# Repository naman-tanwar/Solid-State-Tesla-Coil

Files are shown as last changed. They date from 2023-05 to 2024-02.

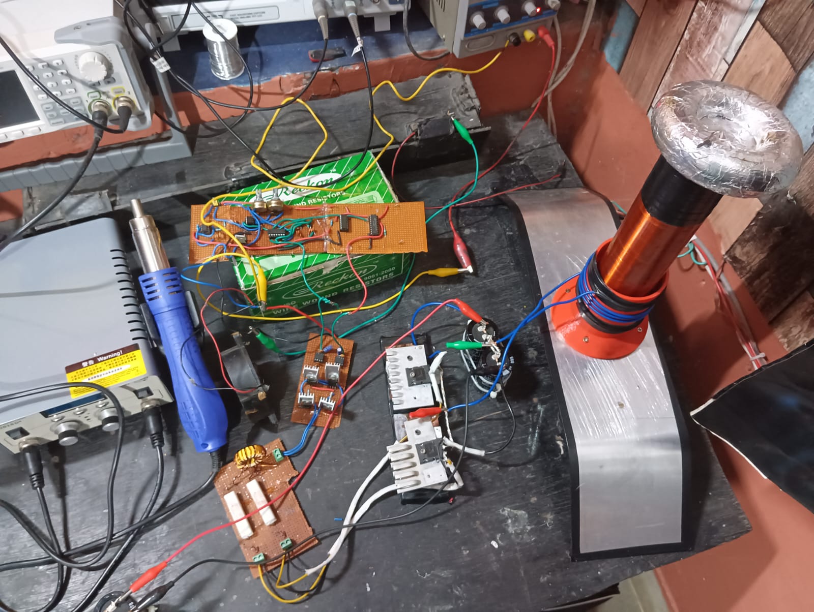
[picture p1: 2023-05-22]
Photos/Setup - Pic2.jpg

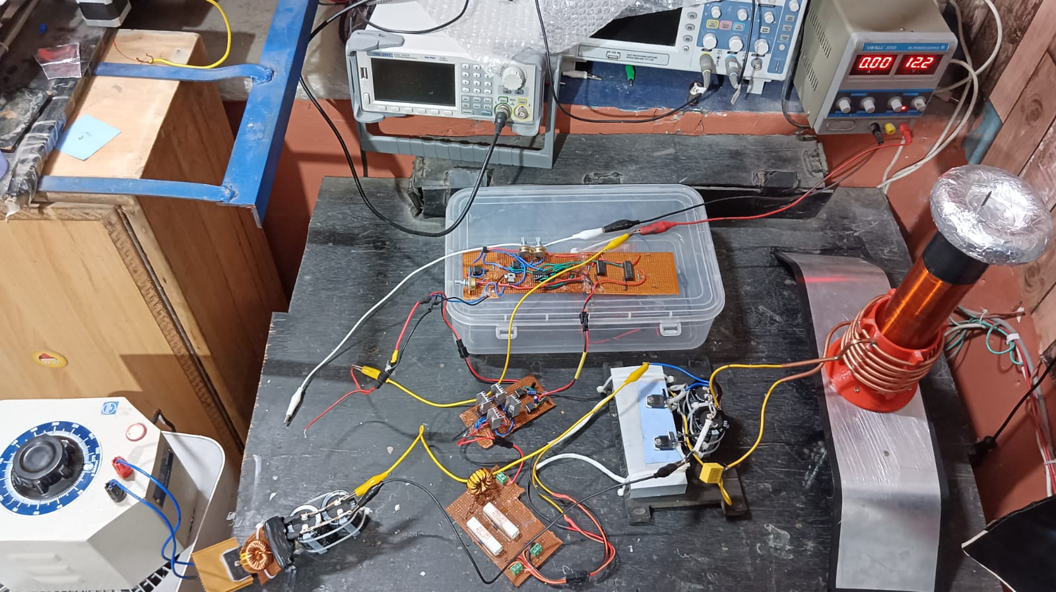
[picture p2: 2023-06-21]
Photos/Setup - Pic3.jpg

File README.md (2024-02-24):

#### This project is published in IEEE Access, do check the complete article: [10.1109/ACCESS.2024.3357534](https://doi.org/10.1109/ACCESS.2024.3357534)
# Solid State Tesla Coil (SSTC)
N|TeslaCoil

## Introduction
Solid State Tesla Coil uses transistor-based switching devices (instead of Spark Gap) to resonate the secondary coil with or without feedback. 
The both kinds of circuits (with and without feedback) were designed and implemented.
The features of the SSTC are:
1. Feedback and without feedback Circuits
2. Variable duty cycle Interrupter
3. Music Interrupter to play music from SSTC
4. PCB Design

## Design
The design of the tesla coil is described below,
### Coil Design
1. Primary Coil  <br>
Primary Coil consist of 5mm copper pipe with 6 turns wound around the secondary with 3D printed support.  <br>
2. Secondary Coil  <br>
The secondary winding are wound around a 2-inch PVC water pipe with 36 gauge copper motor winding wire. The length of the pipe is around 25cm with winding height of 20cm. 5cm of PVC pipe is kept as a margin.
Around 1200 turns of described wire was winded.  <br>
3. Top Load  <br>
The top load was 3D printed in two halves and then aluminium tape was wrapped around it. The tape was wrapped with as much wrinkles as possible to reduce charge loss. The 3D files are available to download on this GitHub page  <br>
5. 3D printed holder for coils  <br>
Using Fusion 360, the coil holder was designed. The files for the holder can also be downloaded from this github page.  <br>

### Circuit Design
As described in the Introduction section, the different circuits were designed to incorporate all the features. Before actually implementing tho, these were simulated using LTSpice. <br>
The Complete circuit diagram and all the simulation files are available on this page.

### PCB Design
N|TeslaCoilPCB

A PCB was designed using Altium. The PCB is a 4 layer board with 100mm x 100mm dimensions. All generic parts THT parts were used in this design.
The features of the PCB are:
1. It uses tuneable non-feedback circuit
2. Can also play music. The music input can be given using 3.5mm mobile AUX cable.
3. Circuit is tested with voltages from 12V to 15V  
<br>
The gerber files, Bill Of Material (BOM), Altium project files and other related documents are available to download from this page.

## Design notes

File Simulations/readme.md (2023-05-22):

# Simulation Info
To verify the design of the tesla coil various simulations were performed using LTspice. These simulations were:

1. Gate Drive Signal Generation

Here we used 555 timer IC (U1) to generate around 730KHz signal. R1, R2 are the potentiometers that can be tuned to produce required frequency.
This signal goes through various Schmitt triggers to produce required output. The R,C,D component reduces the ON pulse width so that a margin of dead time can be created between the two output drives.
The Drive1 is complementary of Drive2 with a little dead time between those two pulses.
Now, an another 555 timer IC (U2) is used to interrupt the produced drive signal at much lower frequency (<1KHz). The duty cycle of the interrupt signal can be adjusted by adjusting R6. Although it will also change the frequency but it will remain less than 1KHz.

2. Music Input

An OPAMP based PWM signal generation from music signal is simulated. Generally, from the mobile audio jack the output voltage is 0.8V peak. Hence it need to be first amplified. The OPAMP U1 amplify the signal and the OPAMP U2 acts as a comparator to output PWM signal.
The reference Voltage of the comparator can be adjusted by adjusting the R5 resistor Value.
In practice, LM358 Dual OPAMP IC was used.

3. Feedback Tesla Coil

This circuit uses an antenna as a feedback to self-sustain the oscillations. (Basically an advance version of Slayer Exciter) Here the interrupter is also implemented by simply connecting the feedback to the interrupt signal through a Diode. 
Resistor selection R1, R2, R3 is also important to reduce overloading effect (in case of R1) and to sustain the oscillations.
Diodes D3 and D4 are to limit input voltage to 5V

4. Diode Voltage Limiting

This circuit simulates the voltage limiting using two fast recovery diodes.

5. Slayer Exciter

Simulates traditional BJT based slayer exciter circuit.

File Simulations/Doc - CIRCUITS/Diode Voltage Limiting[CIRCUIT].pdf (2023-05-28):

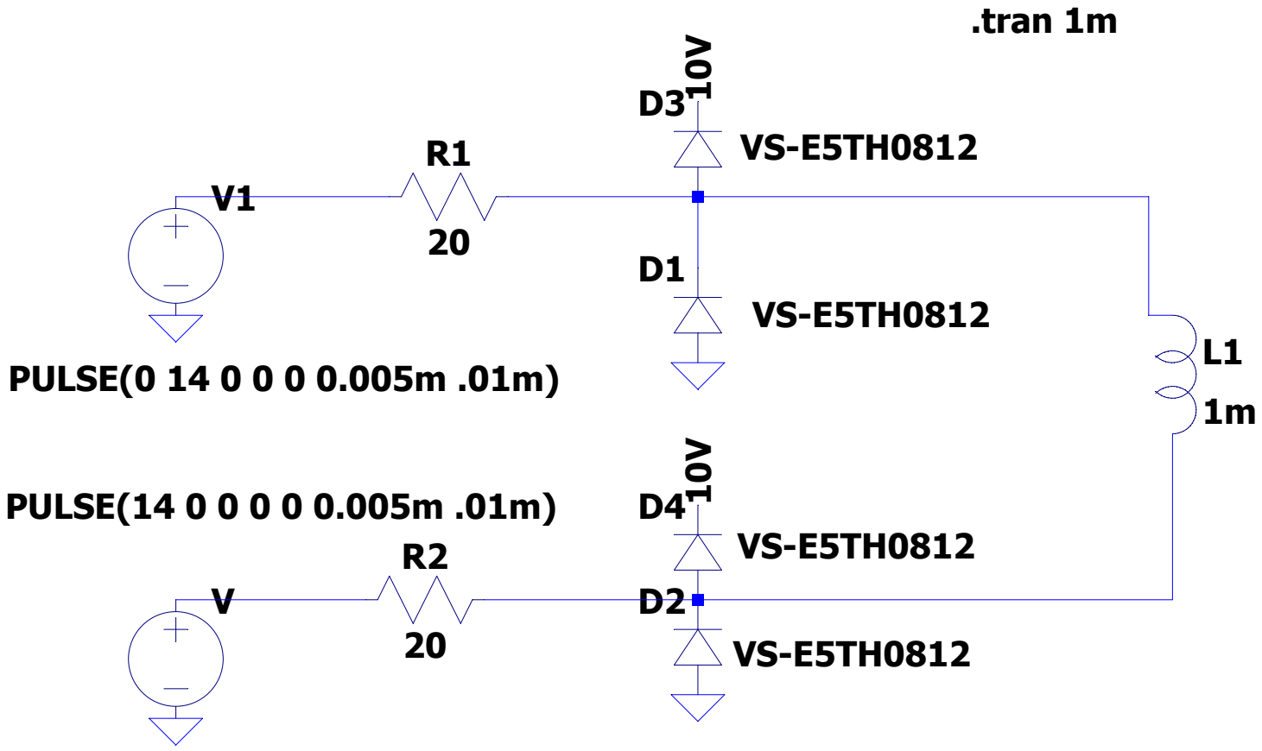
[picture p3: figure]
PULSE(0 14 0 0 0 0.005m .01m); PULSE(14 0 0 0 0 0.005m .01m); .tran 1m

V2

10

10V

## Voltage Limiting using Diodes Simulation

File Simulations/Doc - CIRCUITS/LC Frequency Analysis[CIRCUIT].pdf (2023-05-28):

;tran 1m
At730K
C = 26.55pF

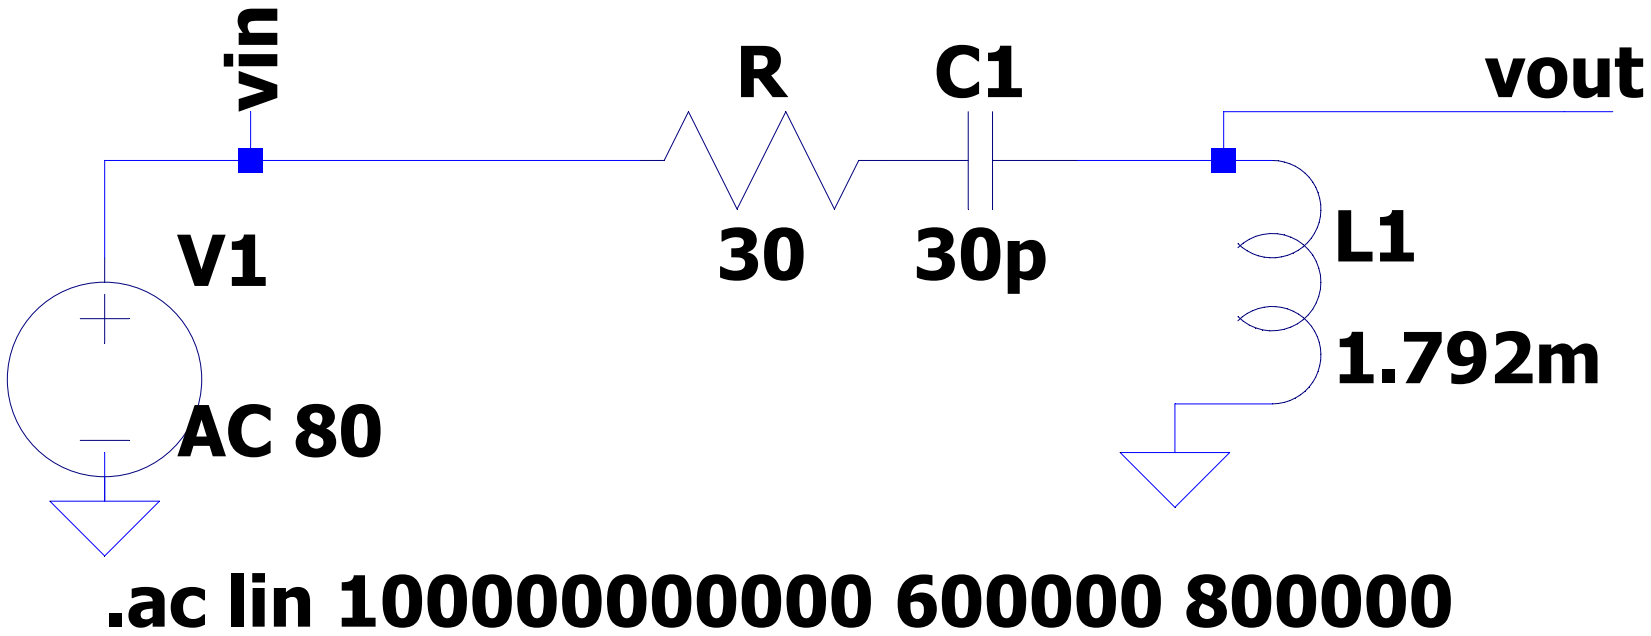
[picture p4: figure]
vinvout; .ac lin 100000000000 600000 800000

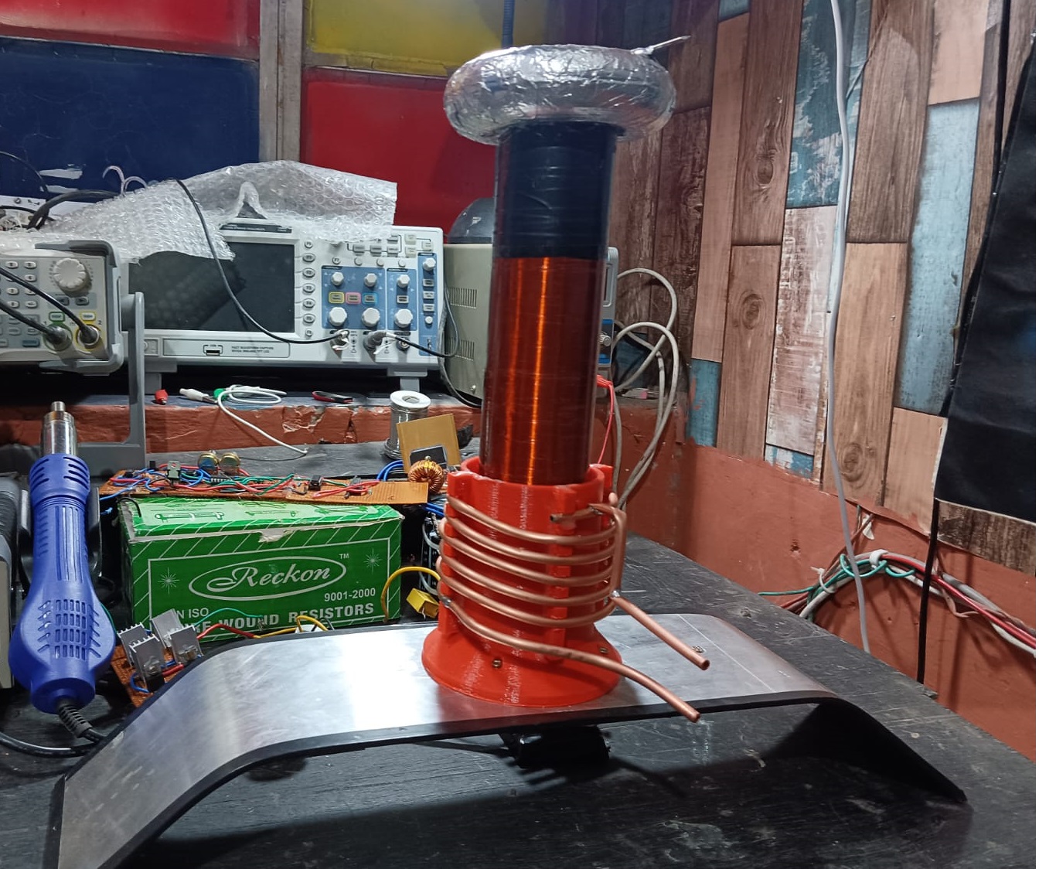
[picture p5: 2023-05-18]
Photos/Tesla Coil - 1.jpg

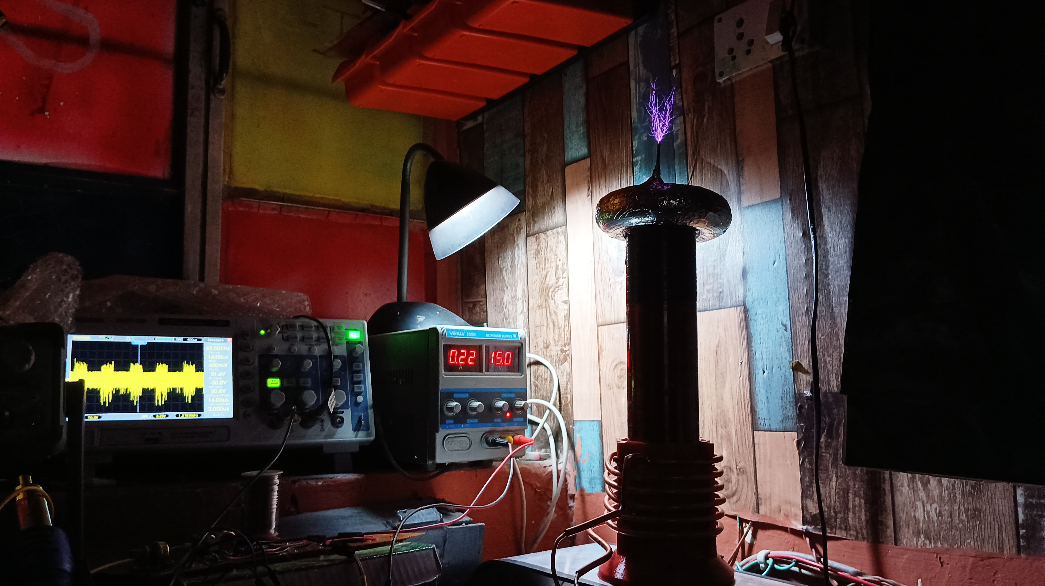
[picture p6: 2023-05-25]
Photos/Tesla Coil - 4.jpg

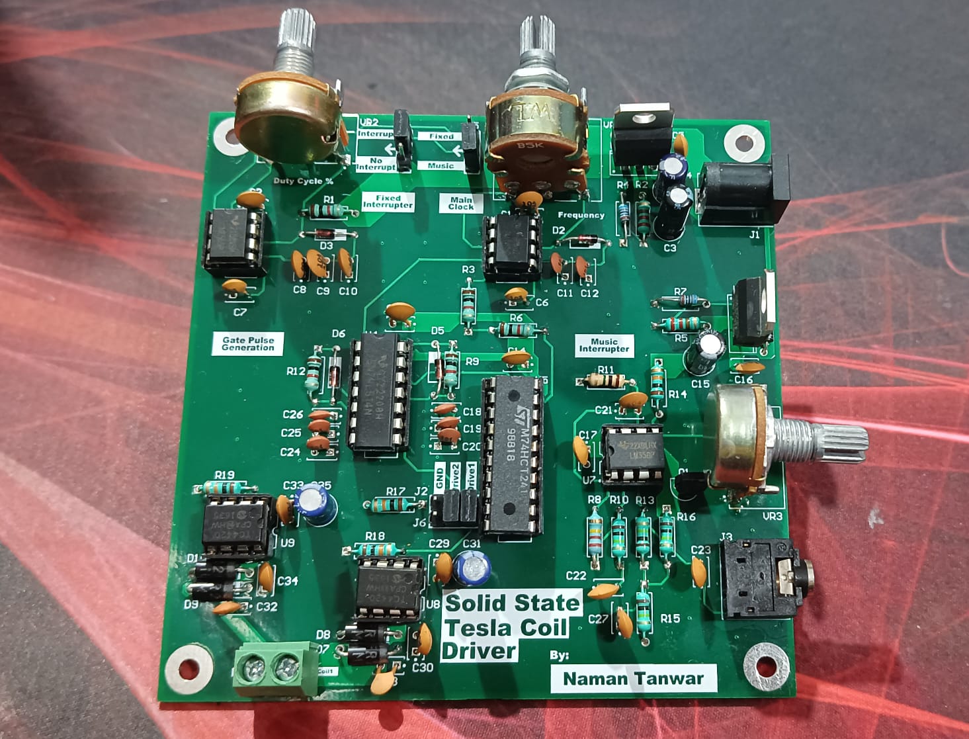
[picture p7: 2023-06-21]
Photos/PCB.jpg

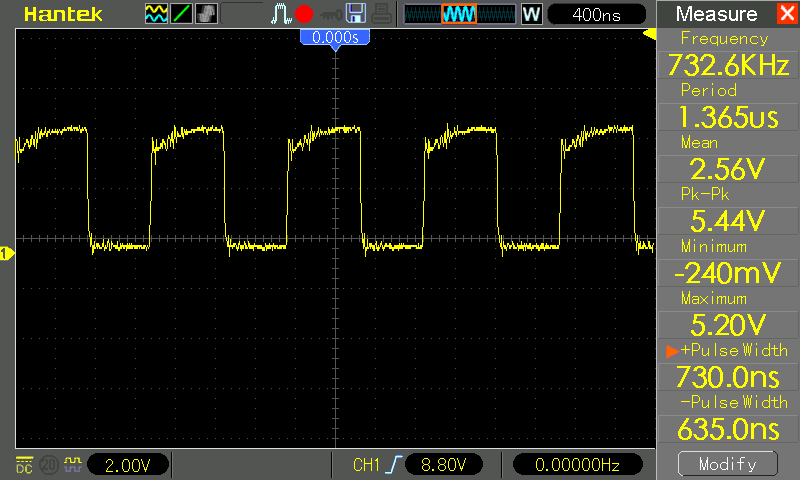
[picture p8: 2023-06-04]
Photos/Scope Reading/730Khz clock generated by main 555 IC.bmp

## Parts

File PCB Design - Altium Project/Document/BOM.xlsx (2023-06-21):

Comment | Description | Designator | Quantity
0.1u | Ceramic Capacitor, 100 nF, +/- 10%, 50 V, -55 to 125 degC, 2-Pin THD, RoHS, Tape and Reel | C1, C2, C5, C8, C9, C10, C13, C14, C16, C17, C21, C22, C23, C27, C29, C30, C33, C34 | 18
2u2 | Aluminum Electrolytic Capacitors (Radial Lead Type) AEC-Q200 Qualified 2.2uF ±20% 50V | C3, C15 | 2
10u | Aluminum Electrolytic Capacitors 10u | C4 | 1
0.01u | Ceramic Capacitor, 10 nF, +/- 10%, 50 V, -55 to 125 degC, 2-Pin THD, RoHS, Tape and Reel | C6, C7 | 2
0.0001u | Ceramic Capacitor, 0.1 nF, +/- 10%, 50 V, -55 to 125 degC, 2-Pin THD, RoHS, Tape and Reel | C11, C12, C18, C19, C20, C24, C25, C26 | 8
0.001u | Ceramic Capacitor, 1 nF, +/- 10%, 50 V, -55 to 125 degC, 2-Pin THD, RoHS, Tape and Reel | C28, C32 | 2
4u7 | Aluminum Electrolytic Capacitors (Radial Lead Type) AEC-Q200 Qualified 4u7uF ±20% 50V | C31, C35 | 2
1N4007 | 1N4007 Generic Diode | D1, D4 | 2
1N4148 | High Speed Diode, 100 V, 0.45 A, -65 to 175 degC, 2-Pin SOD27, RoHS, Bulk | D2, D3, D5, D6 | 4
FR207 | MULTICOMP FR207 Standard Power Diode fast diode, Single, 1 kV, 2 A, 1.2 V, 60 A, 150 C | D7, D8, D9, D10 | 4
4840.2201 | DC Connector Socket 6x2mm 2-Pole 12VDC 0.5A 500VDC Dielectric Solder Term PCB Mt | J1 | 1
HDR 1X3 | Conn Unshrouded Header HDR 3 POS 2.54mm Solder ST Top Entry Thru-Hole BergStik® Automotive Bulk | J2, J4, J5, J6, J7 | 5
AUX Conn | 3.5 mm Right-Angle Stereo Jack, 3 Pin PCB Mount, Isolated Ground | J3 | 1
2N3904BU | NPN General-Purpose Amplifier, 40 V VCEO, 0.2 A, -55 to 150 degC, 2-Pin TO-92, RoHS, Bulk | Q1 | 1
1k | Axial Resistor, 1 KOhm, +/- 1%, 250 mW, -55 to 155 degC, 2-Pin THD, RoHS, Bulk | R1, R3, R6, R9, R12 | 5
220R | Axial Resistor, 220 Ohm, | R2, R5 | 2
680R | Axial Resistor, 680 Ohm, | R4, R7 | 2
220k | Axial Resistor, 220 KOhm, | R8 | 1
100k | Axial Resistor, 100 KOhm | R10, R13, R15, R16 | 4
1M | Axial Resistor, 1 MOhm, | R11 | 1
10k | Axial Resistor, 10 KOhm, +/- 1%, 250 mW, -55 to 155 degC, 2-Pin THD, RoHS, Bulk | R14, R17, R18, R19, R20 | 5
NE555P | Precision Timer, 4.5 to 16 V, 0 to 70 degC, 8-Pin DIP, Pb-Free, Tube | U1, U2 | 2
LM317T | Integrated Circuit 3-terminal Positive Adjustable Voltage Regulator TO-220 Case 1.2 To 37 Volts | U3, U6 | 2
SN74LS14N | Hex schmitt-trigger inverters, N0014A, TUBE | U4 | 1
CD74HCT241E | High Speed CMOS Logic Non-Inverting Octal Buffer/Line Drivers with 3-State Outputs, N0020A, TUBE | U5 | 1
LM358AP | Dual Operational Amplifier, 3 to 32 V, 0 to 70 degC, 8-Pin PDIP (P), Pb-Free (RoHS), Tube | U7 | 1
TC4420CPA | 6A High-Speed MOSFET Driver, Non-Inverting, Commercial Temperature | U8, U9 | 2
5K Dual Gang POT |  | VR1 | 1
10K POT | Diameter Panel Control, 10 KOhm, +/- 10%, 2 W, -1 to 125 degC, 3-Pin THD, RoHS, Bulk | VR2 | 1
1K POT | Diameter Panel Control, 1 KOhm, +/- 10%, 2 W, -1 to 125 degC, 3-Pin THD, RoHS, Bulk | VR3 | 1

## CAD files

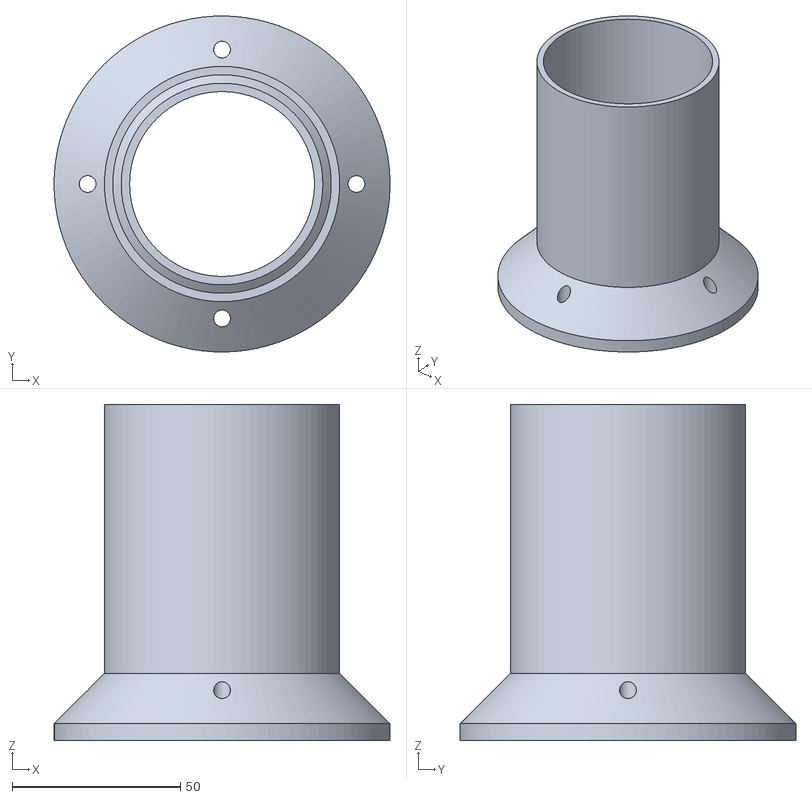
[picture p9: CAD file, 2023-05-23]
3D Files/Coils Holder.stl
100.0 x 100.0 x 100.0

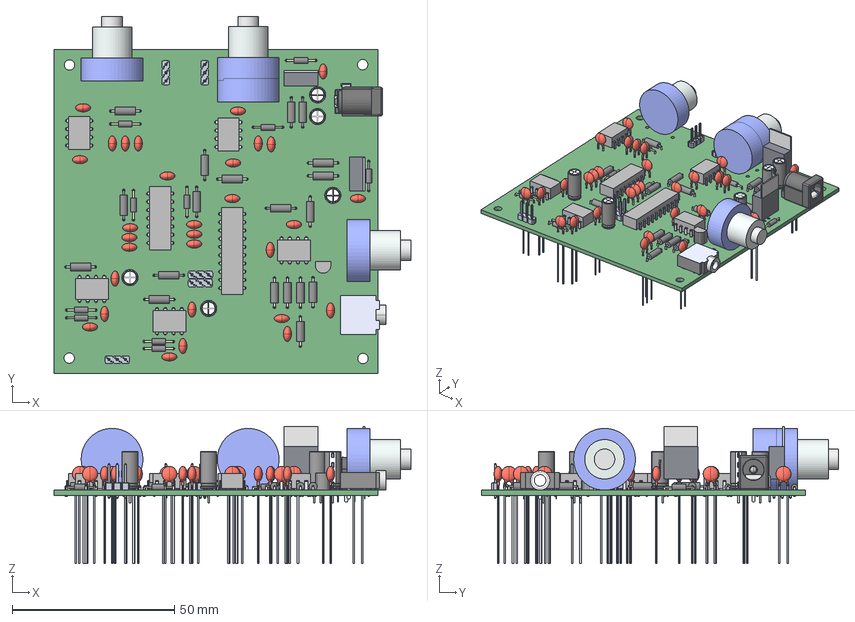
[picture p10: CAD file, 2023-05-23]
PCB Design - Altium Project/Document/SolidStateTeslaCoil_PCB_3D.step
110.1 x 110.2 x 42.4 mm
marking x 5
bottom x 5
logo x 5
polarity marking x 5
top x 5
terminal x 5
10pF Ceramic Disc 3 x 30
Extruded x 234
HDR 1X3 x 5
CUI_DEVICES_SJ1-3523NG
DC Power Jack 5.5mm x 2.1mm

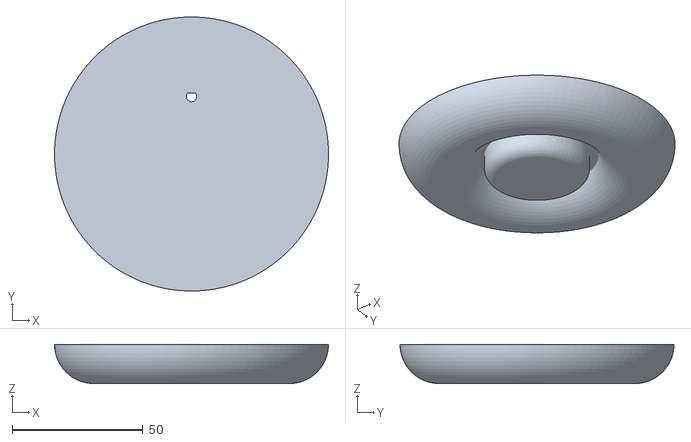
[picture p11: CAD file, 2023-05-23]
3D Files/Tol Load Bottom.stl
105.0 x 105.0 x 15.0

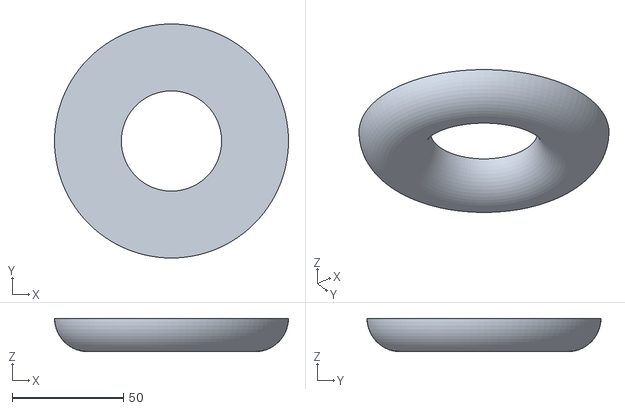
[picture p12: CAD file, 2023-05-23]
3D Files/TopLoad Top.stl
105.0 x 105.0 x 15.0

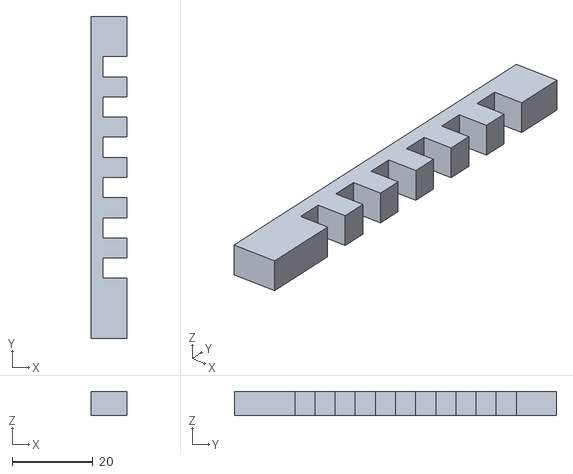
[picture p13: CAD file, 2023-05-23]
3D Files/Primary Holder extra attachment.stl
9.00 x 80.0 x 6.00

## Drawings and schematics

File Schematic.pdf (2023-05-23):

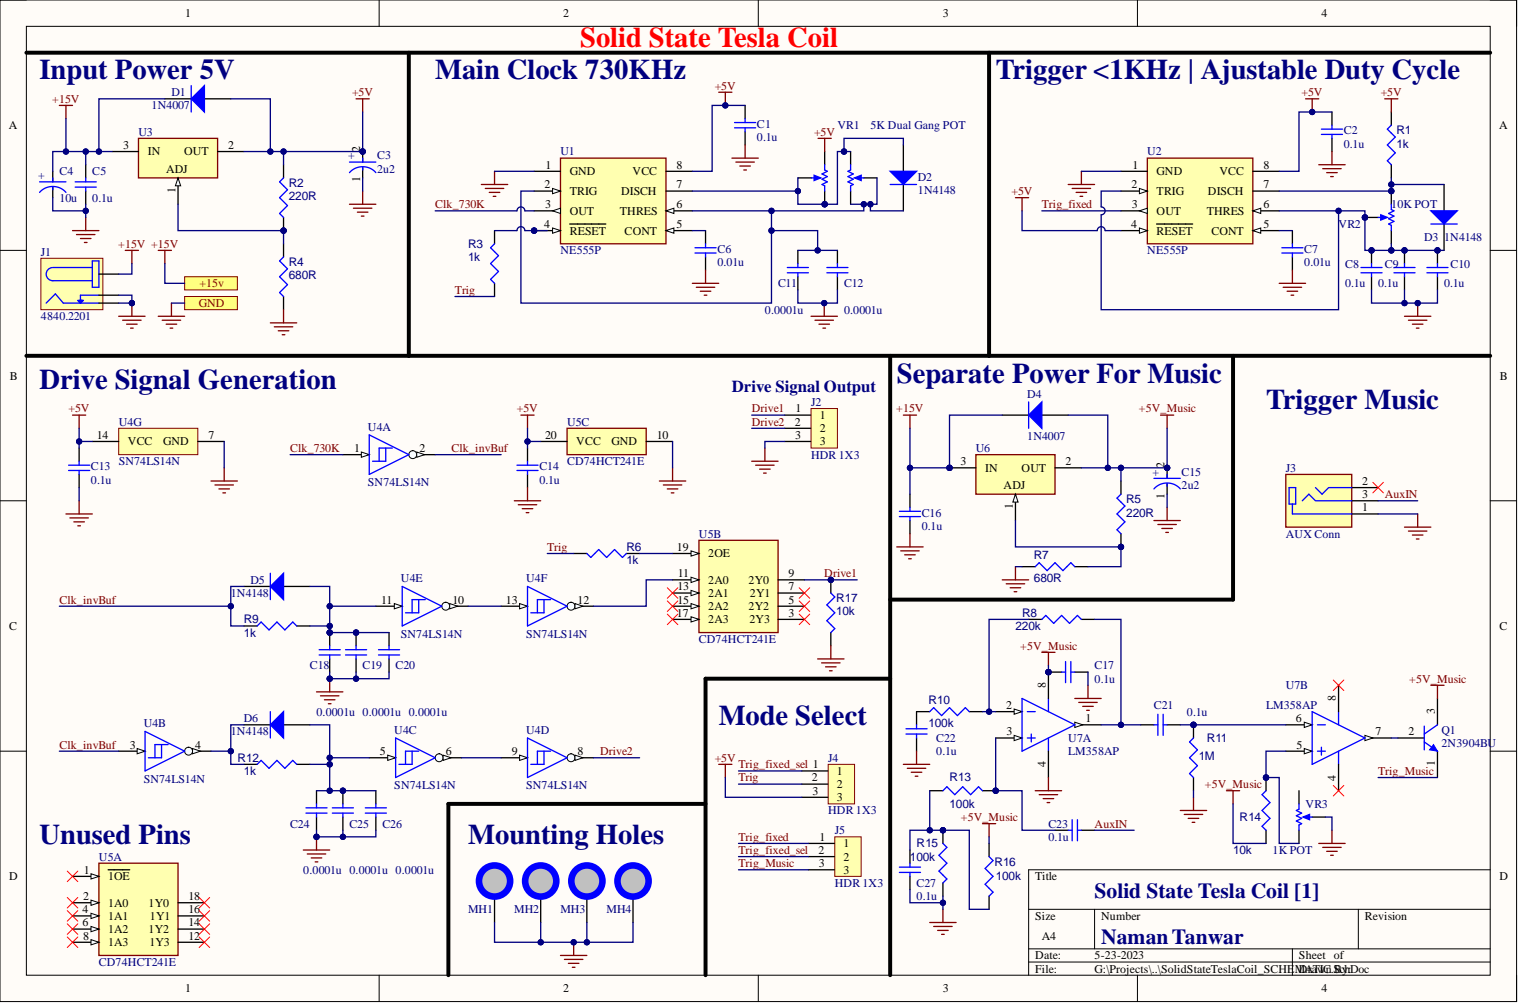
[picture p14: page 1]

Solid State Tesla Coil

Trigger <1KHz | Ajustable Duty Cycle

Separate Power For Music

Solid State Tesla Coil [1]

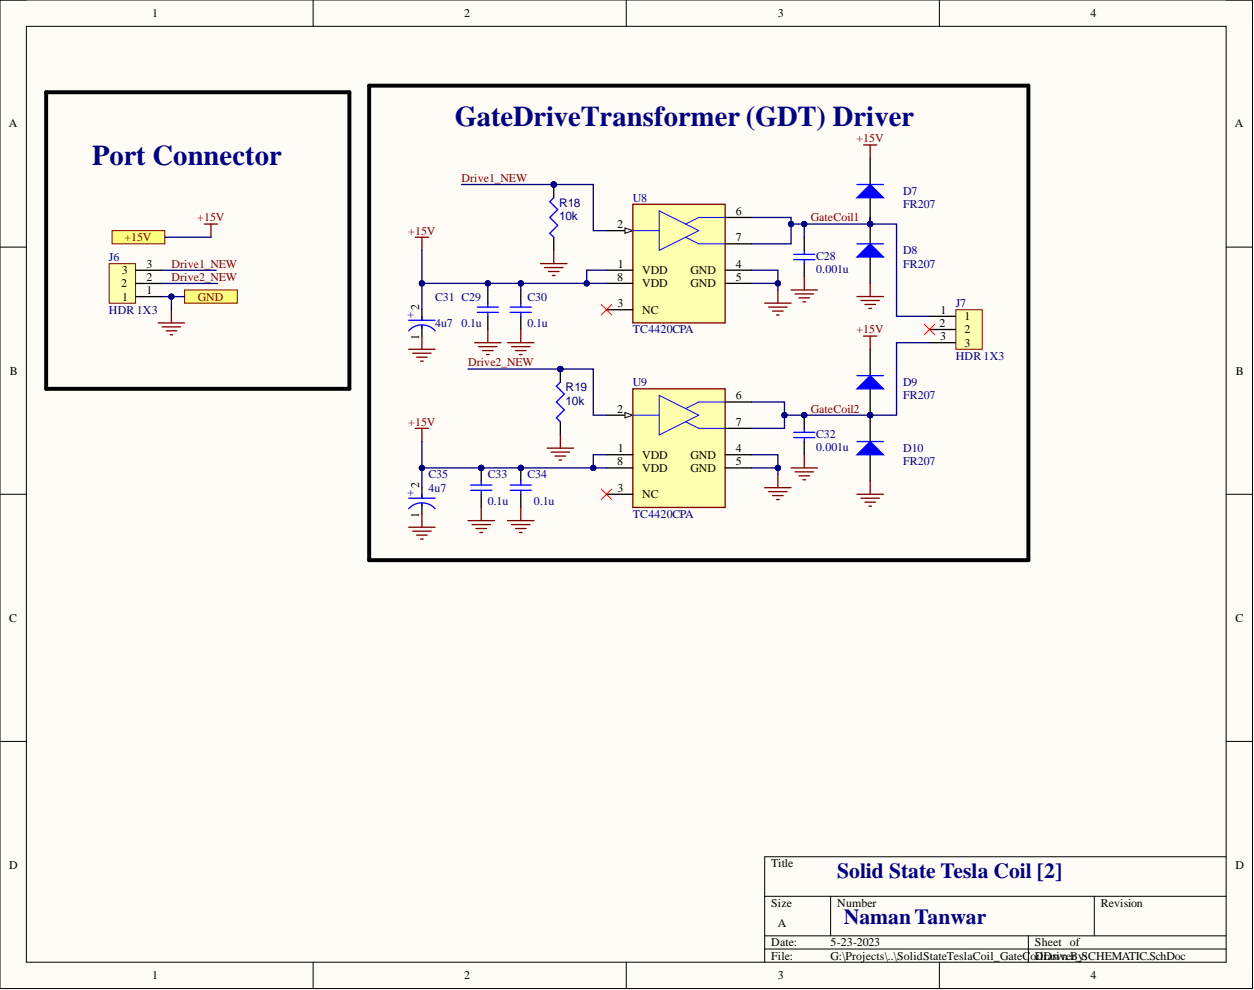
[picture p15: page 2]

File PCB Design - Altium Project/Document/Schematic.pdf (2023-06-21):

Input Power 5V | Main Clock 730KHz

# Trigger <1KHz | Ajustable Duty Cycle

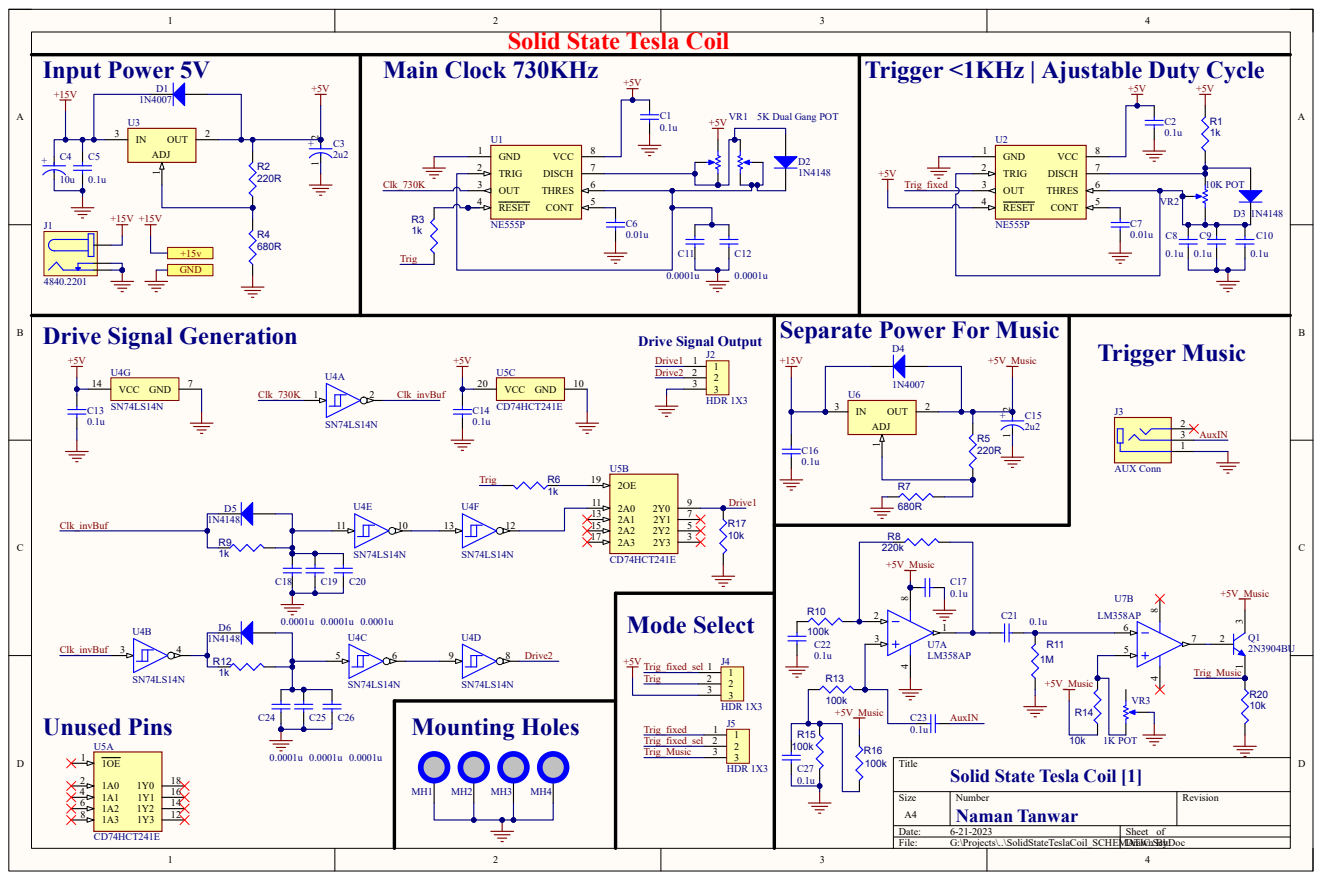
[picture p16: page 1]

Solid State Tesla Coil

Separate Power For Music

Title
Solid State Tesla Coil [1]

# GateDriveTransformer (GDT) Driver Port Connector

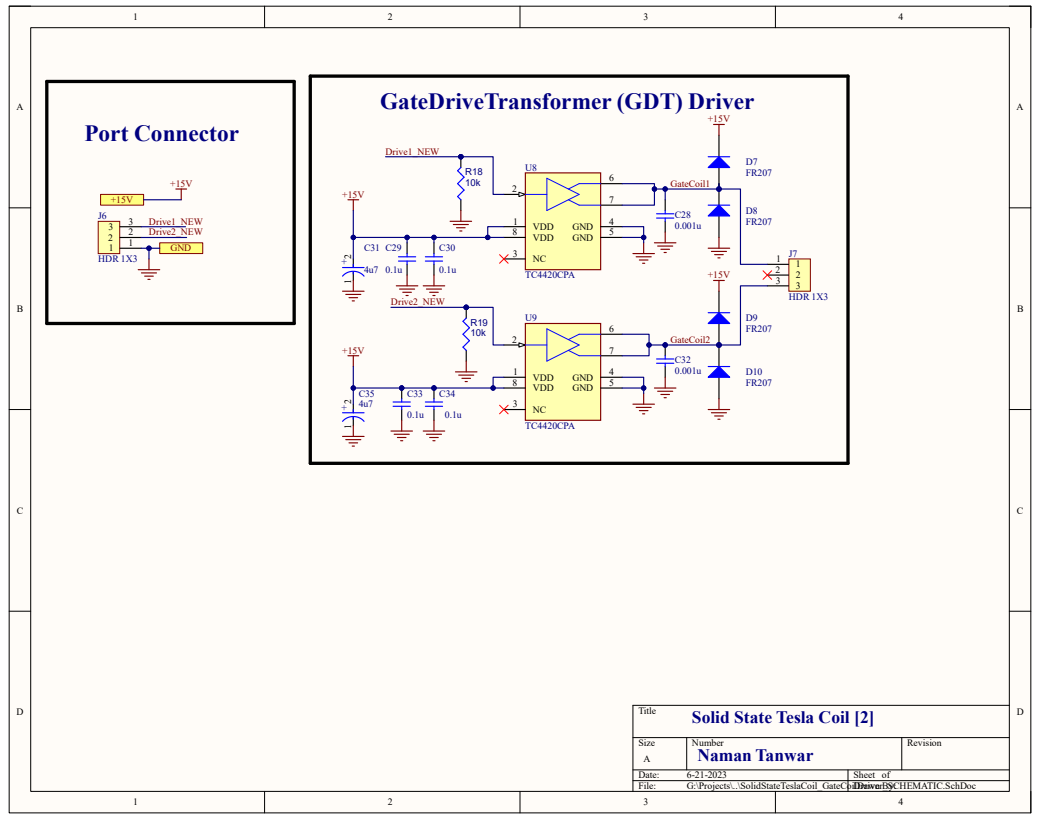
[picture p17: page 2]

Title
Solid State Tesla Coil [2]

Q2 3

IGBT Driver | 1 2

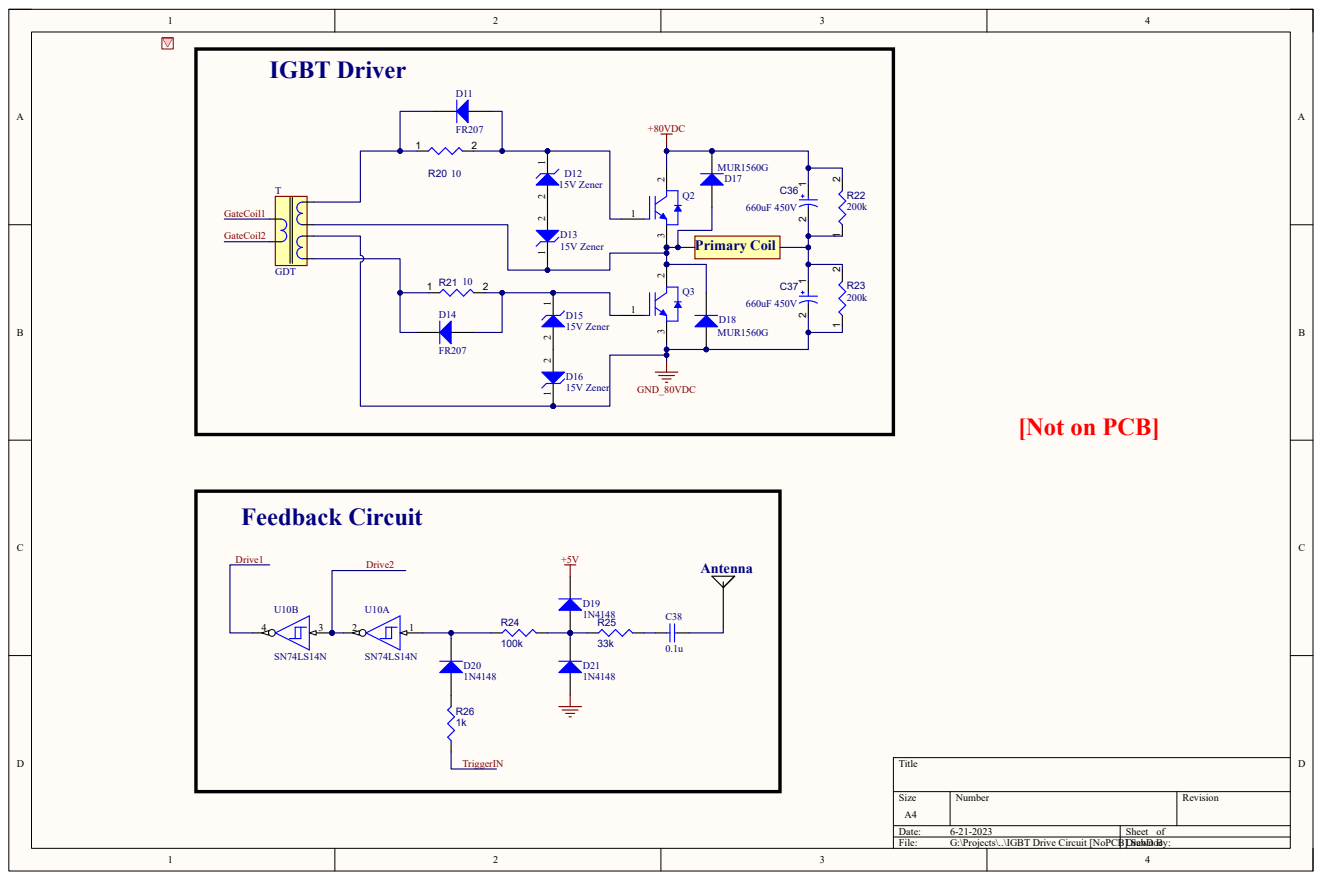
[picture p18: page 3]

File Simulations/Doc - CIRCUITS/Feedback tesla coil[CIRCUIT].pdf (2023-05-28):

## .tran 10m startup

# Solid State Tesla Coil with Feedback

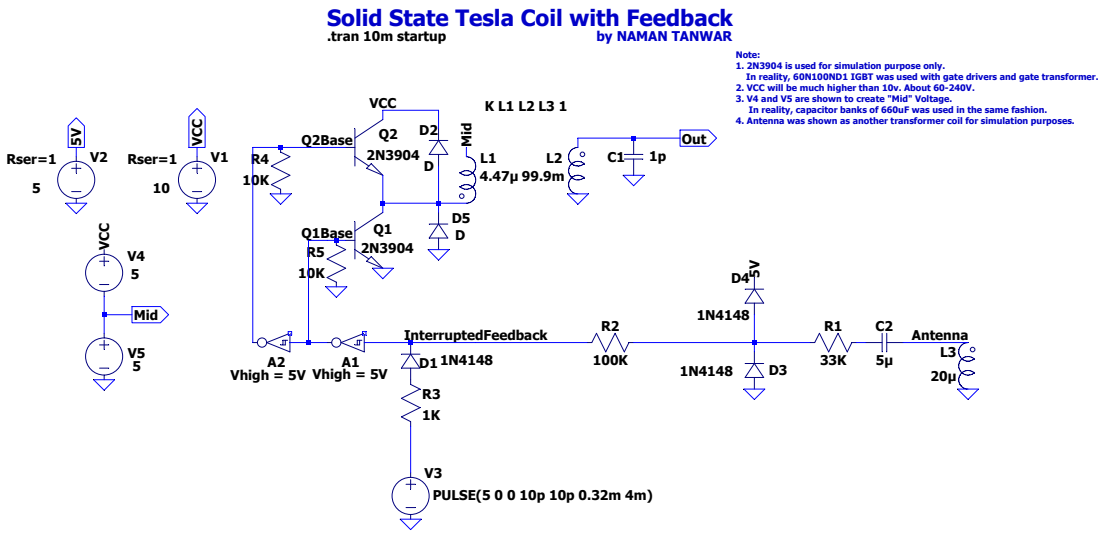
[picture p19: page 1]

Note:
1. 2N3904 is used for simulation purpose only.
In reality, 60N100ND1 IGBT was used with gate drivers and gate transformer.
2. VCC will be much higher than 10v. About 60-240V.
3. V4 and V5 are shown to create "Mid" Voltage.
In reality, capacitor banks of 660uF was used in the same fashion.
4. Antenna was shown as another transformer coil for simulation purposes.

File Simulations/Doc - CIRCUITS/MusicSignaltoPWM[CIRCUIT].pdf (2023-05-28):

## OPAMP based music signal to PWM signal (For Tesla Coil Interrupter)

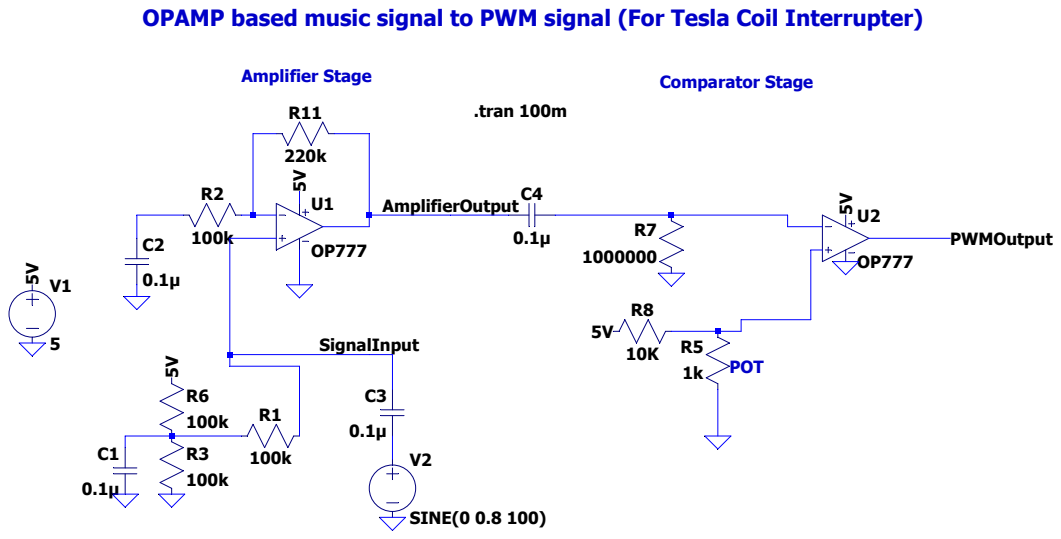
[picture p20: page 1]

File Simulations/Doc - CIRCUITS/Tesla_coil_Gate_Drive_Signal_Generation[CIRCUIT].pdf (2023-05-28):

# Tesla Coil Drive Signal Generation

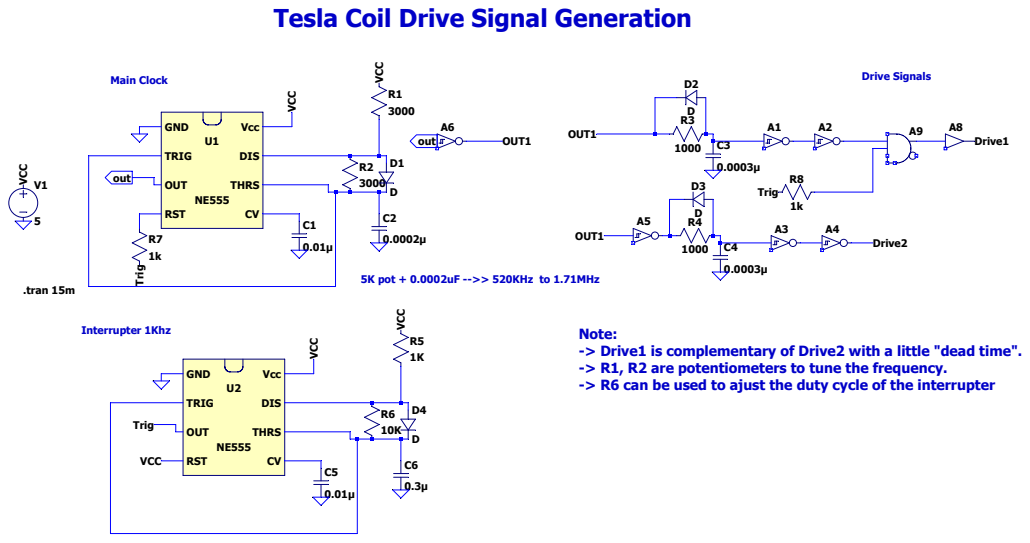
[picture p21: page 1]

Note:
-> Drive1 is complementary of Drive2 with a little "dead time".
-> R1, R2 are potentiometers to tune the frequency.
-> R6 can be used to ajust the duty cycle of the interrupter

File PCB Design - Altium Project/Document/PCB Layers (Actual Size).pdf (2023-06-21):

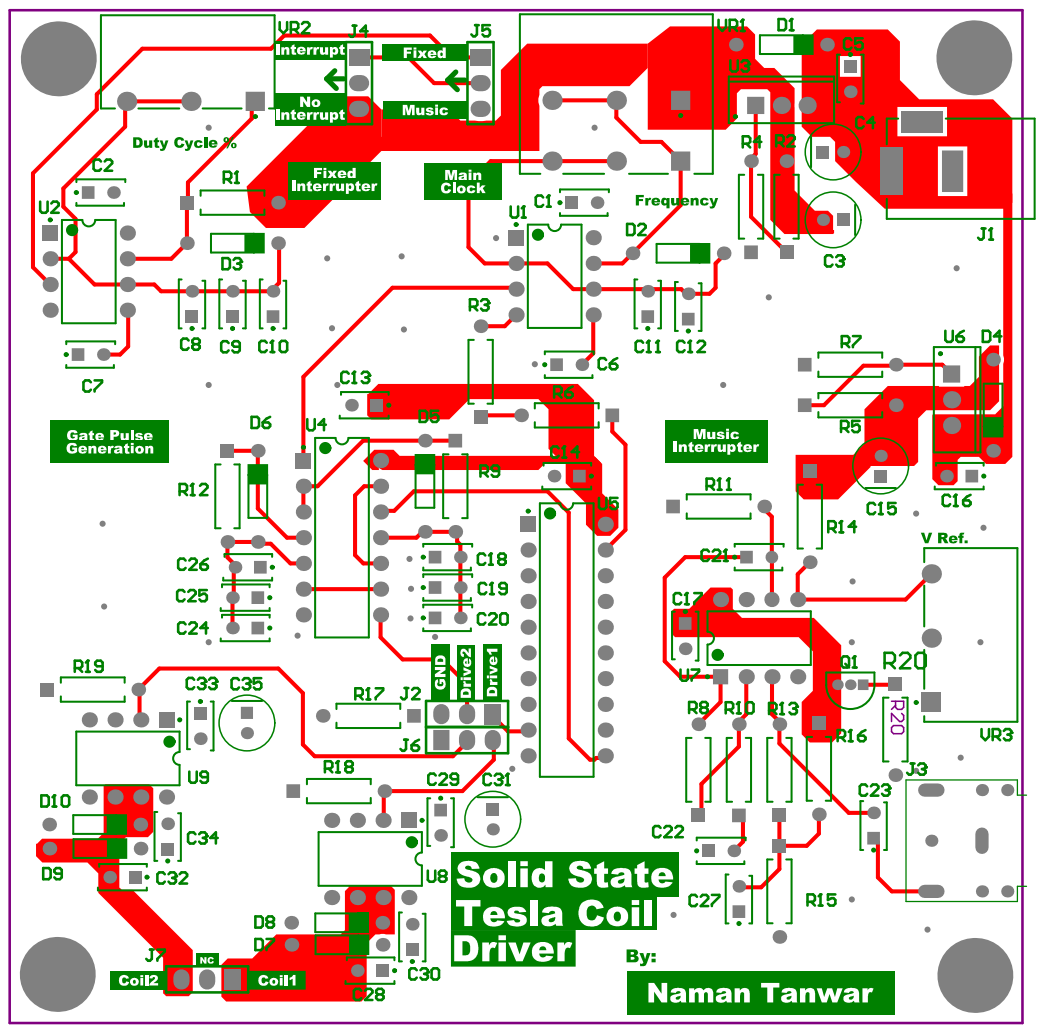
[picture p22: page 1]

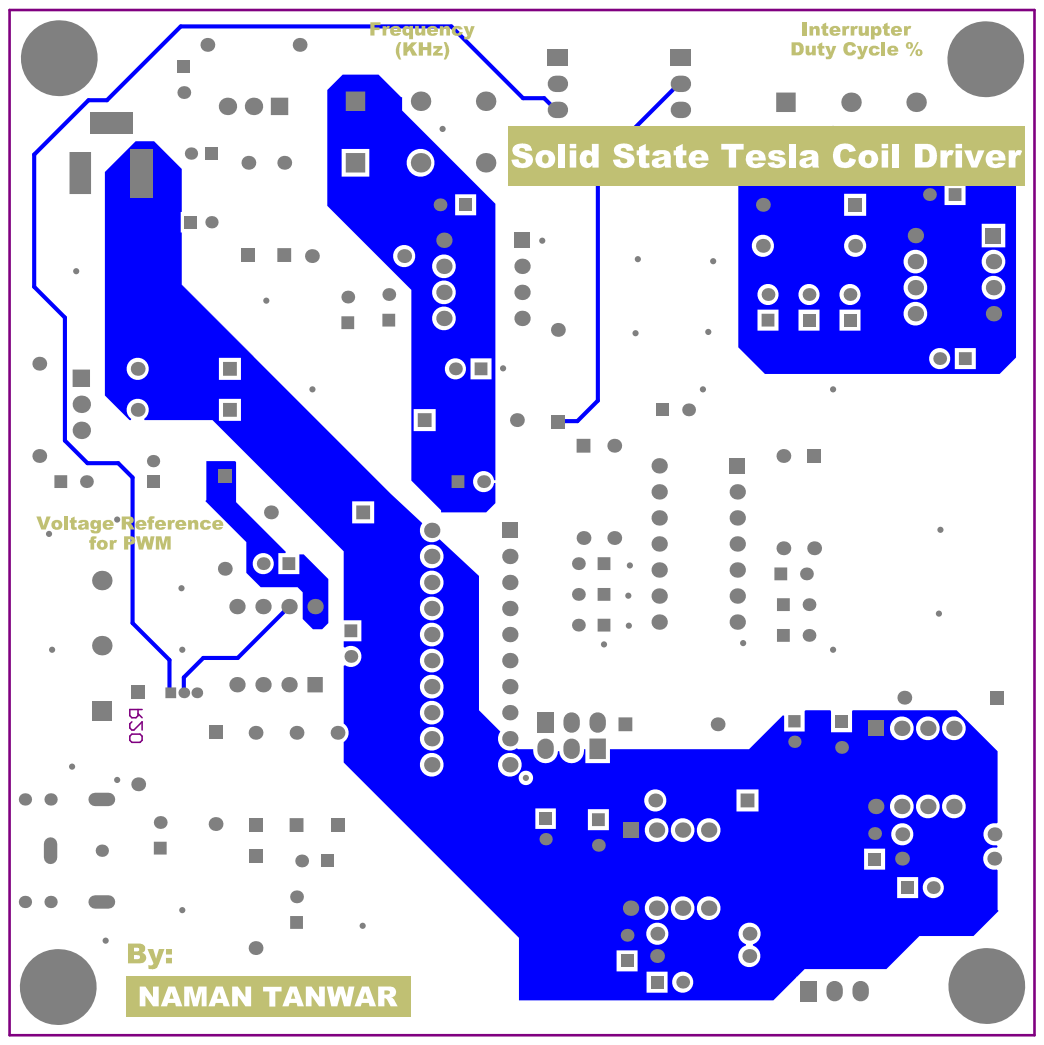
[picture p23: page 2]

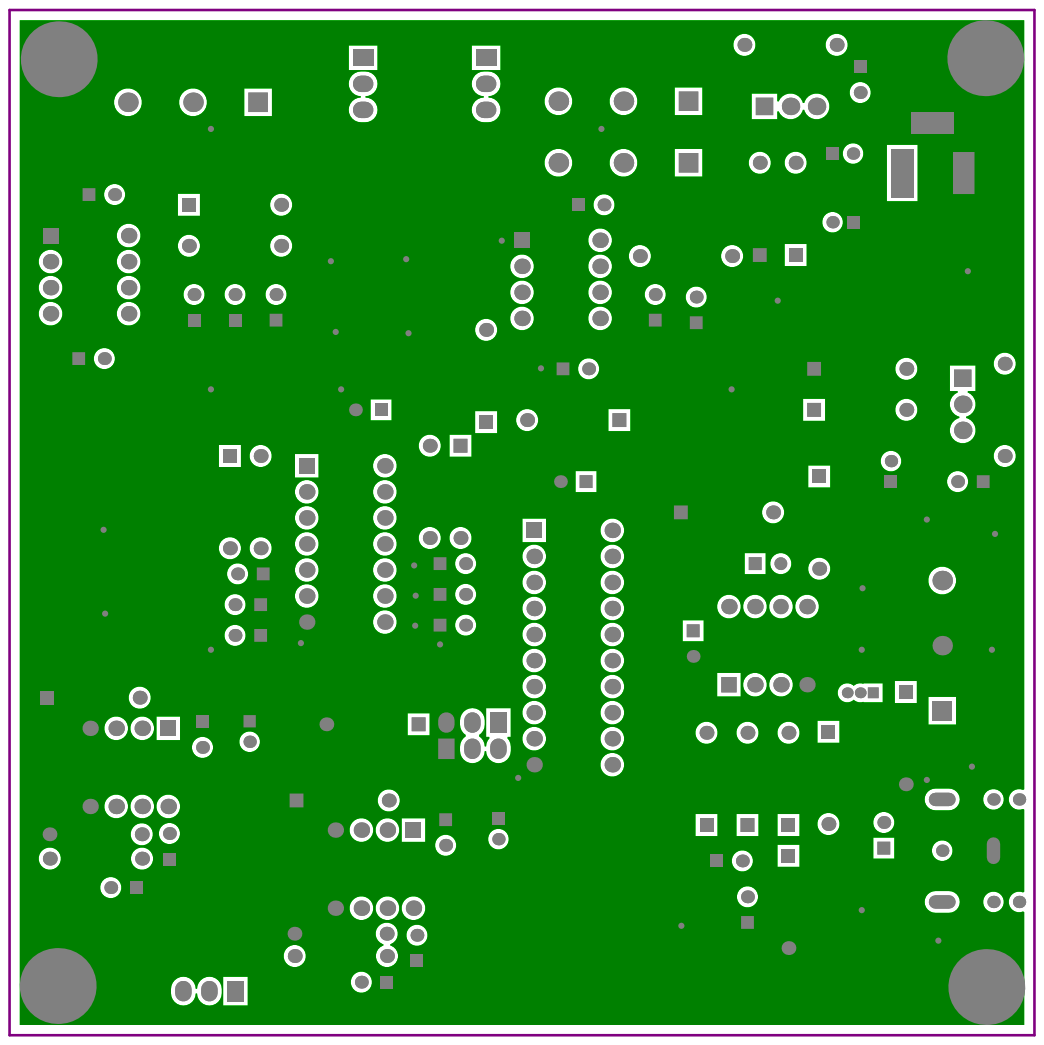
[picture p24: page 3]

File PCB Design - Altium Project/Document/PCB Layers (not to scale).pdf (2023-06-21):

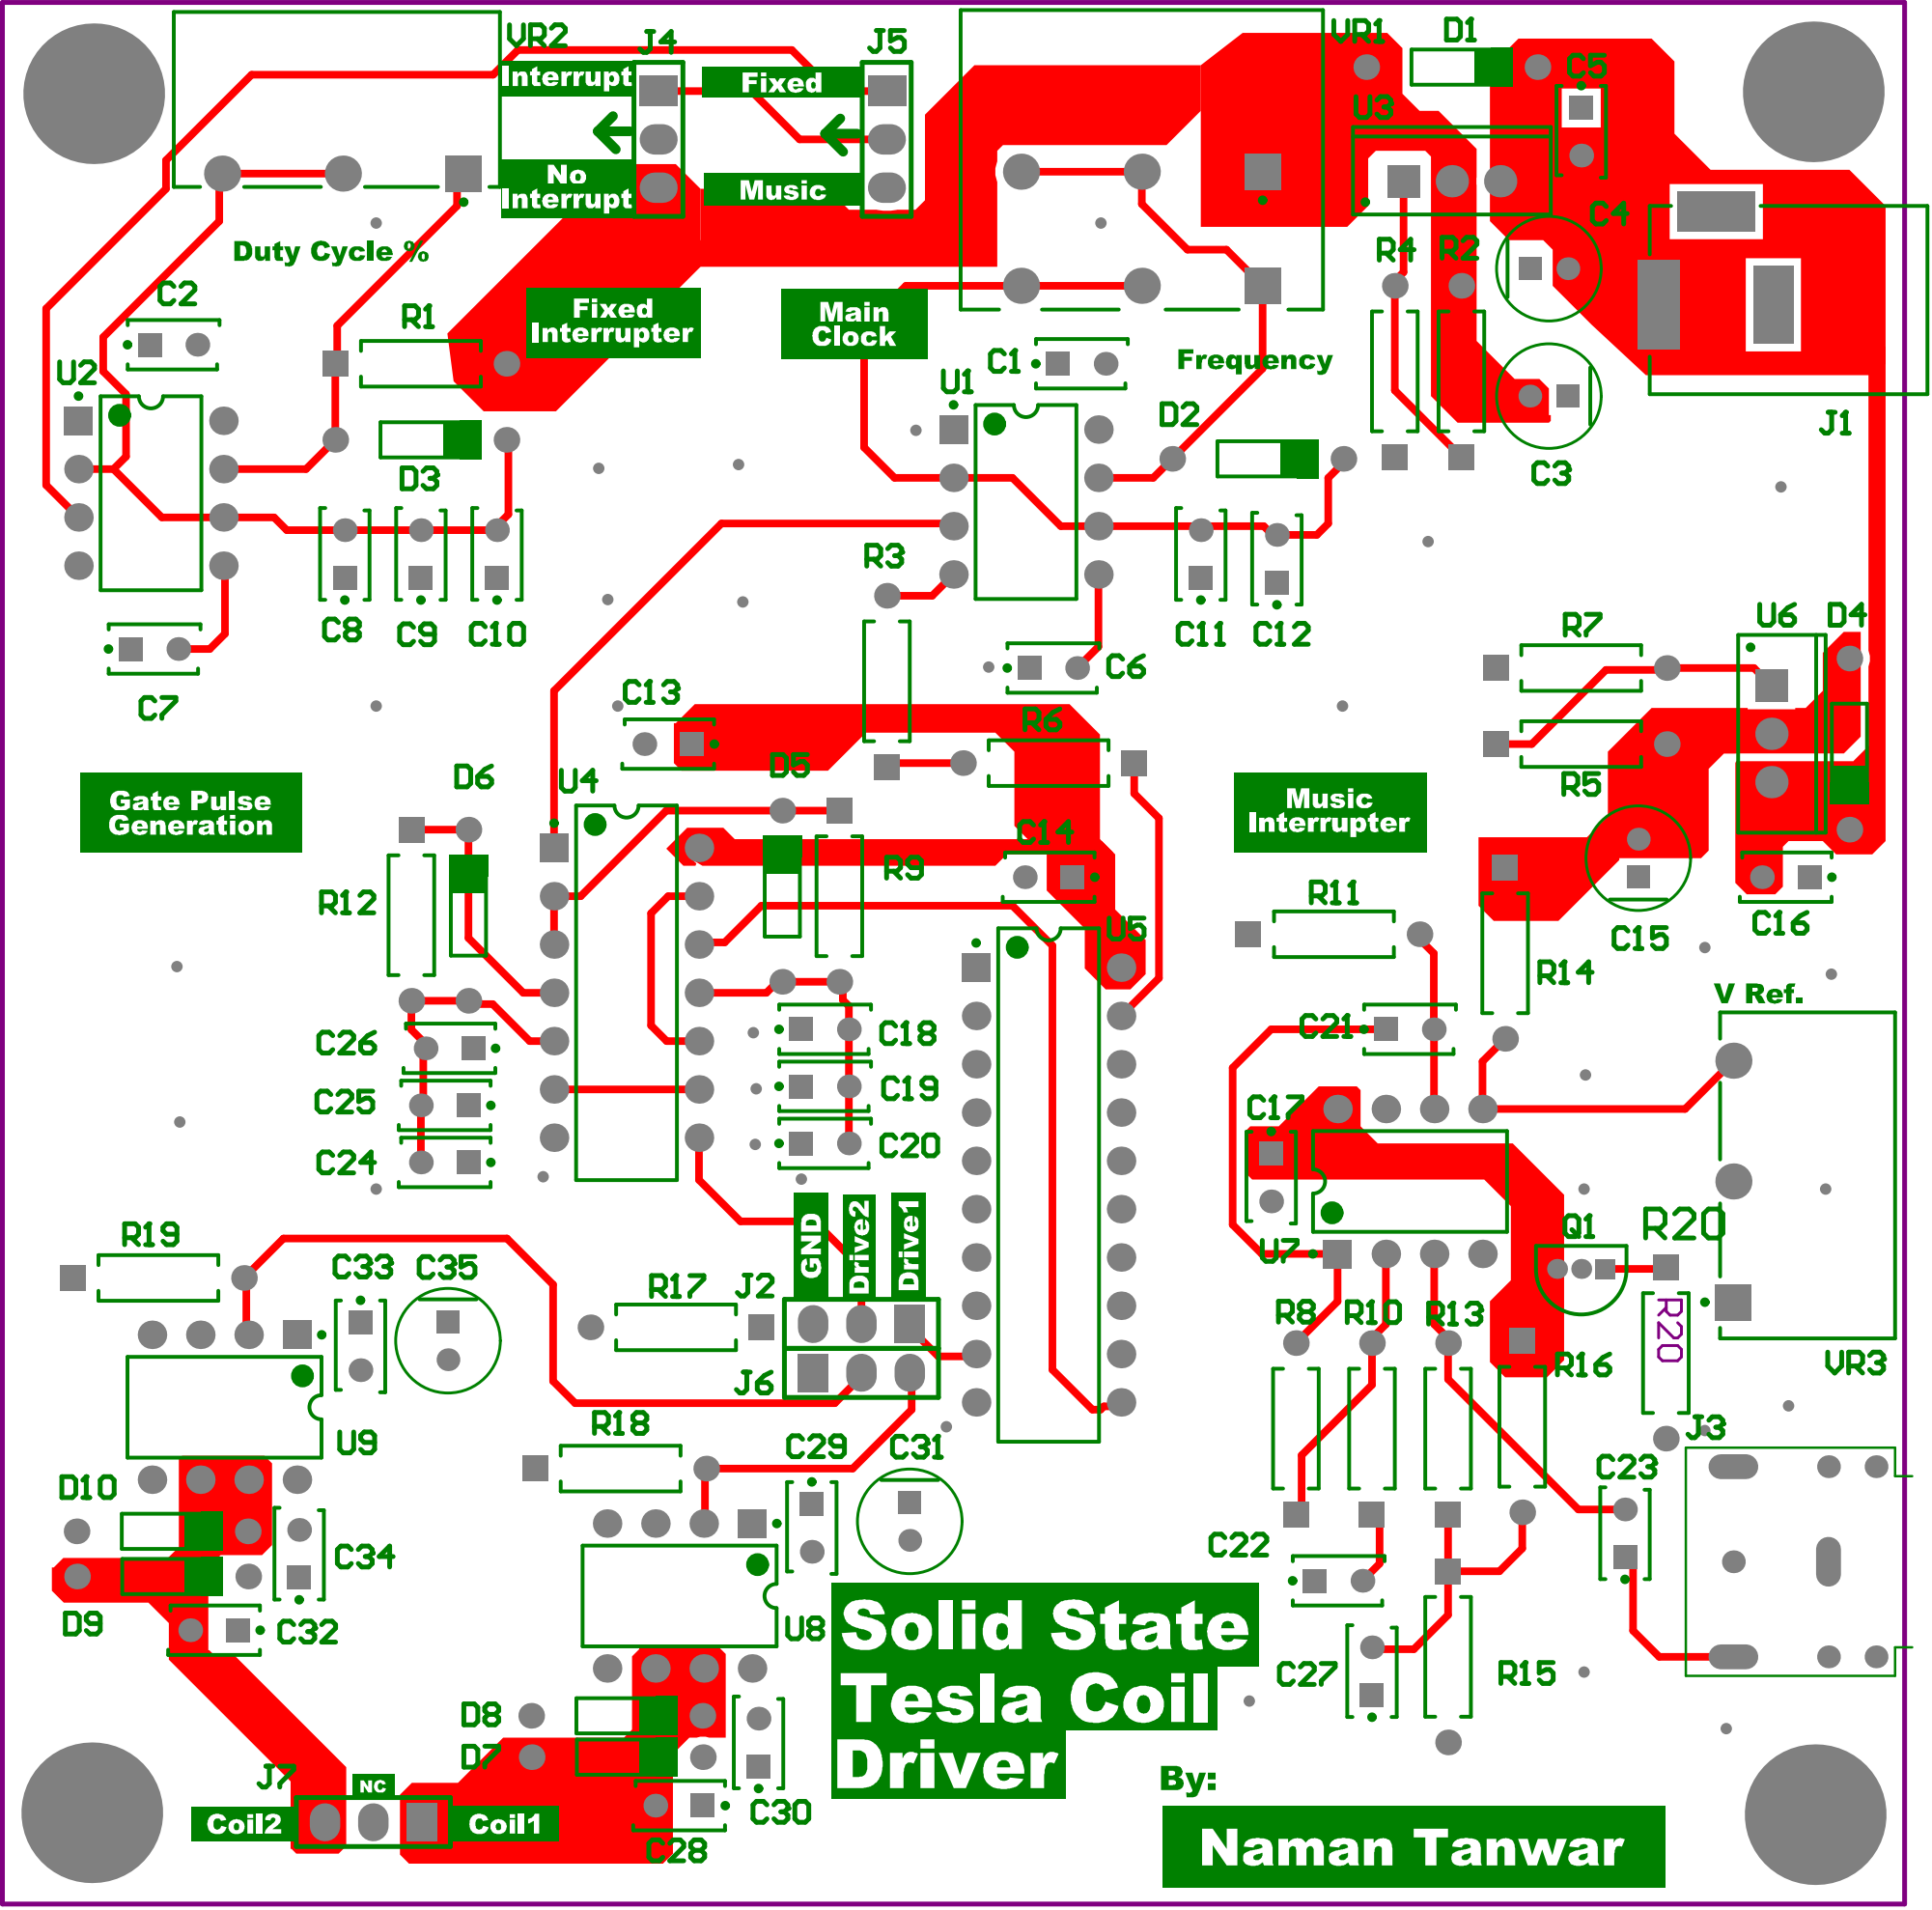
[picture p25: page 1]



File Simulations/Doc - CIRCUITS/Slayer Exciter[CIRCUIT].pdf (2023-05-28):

Rser=1; .tran .1m startup

TRADITIONAL SLAYER EXCITER
